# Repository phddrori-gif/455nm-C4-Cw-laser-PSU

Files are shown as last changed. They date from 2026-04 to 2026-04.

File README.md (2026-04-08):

# 455 nm 151 W Laser Array

## Overview
This repository documents the design, assembly, and testing of a 455 nm, 151 W diode laser array system built for high-power laser experimentation and materials research. The project combines optical, electrical, thermal, and safety engineering to create a controlled platform for evaluating laser performance and exploring laser-heated crystal growth.

## Project Objectives
- Achieve the full 151 W output of the diode array
- Explore laser-based growth of synthetic ruby
- Evaluate whether the system can be adapted for additional materials, including sapphire

## Current Status
The laser platform is operational in several core areas, with major progress completed in the safety, electrical, and mechanical subsystems. Remaining work is focused on characterization, documentation, and material-processing experiments.

## Safety Systems
Because this project involves a high-power 455 nm laser source, safety controls were treated as a primary design requirement.

Implemented safety features:
- OD8+ laser safety eyewear rated for 455 nm
- Hall-effect current sensing with ESP32-based monitoring
- Temperature-based automatic shutdown
- Emergency stop (E-stop)

## Mechanical and System Assembly
Completed design and integration work includes:
- 3D CAD model for the laser and circuit assembly
- Circuit design and schematic development
- PCB layout
- Custom lens holder
- Hybrid cooling system using both water cooling and forced-air cooling

## Electrical and Control Design
Completed electrical work:
- Tested PWM control and mechanical switch logic
- Verified full-wave rectifier suitability for 120 V AC input
- Integrated an IRM-05-3.3 power supply for the Teensy 4.0 controller
- Selected a 5.6 kOhm thermistor reference resistor based on a maximum expected operating temperature of 75 C

In progress:
- Fully label and reorganize the circuit diagram into clearly separated functional blocks

## Optical and Thermal Work
Completed:
- Selected a candidate focal length for the lens system (approximately +30 cm)

In progress:
- Determine the diode array's maximum allowable thermal load
- Measure and verify the optical power output of the diode array

## Materials and Crystal Growth Experiments
Completed:
- Acquired crucible for high-temperature material tests
- Acquired aluminum powder and chromium oxide for ruby experiments
- Planned work to be conducted in a fume hood

Planned:
- Acquire aluminum powder and iron oxide for sapphire experiments
- Evaluate the addition of titanium oxide for blue sapphire trials

## Next Steps
- Complete final circuit documentation
- Characterize thermal limits of the diode array
- Measure output power under controlled operating conditions
- Begin laser-heated ruby growth experiments
- Expand testing to additional materials if ruby trials are successful

## Resume Highlights
This project demonstrates experience in:
- High-power laser system integration
- Embedded monitoring and safety interlocks
- PCB and circuit design
- Thermal management
- Experimental hardware development
- Applied materials research

## Disclaimer
This repository documents work involving high-power laser equipment and high-temperature material processing. Testing should only be performed with proper protective equipment, controlled procedures, and appropriate lab safety infrastructure.

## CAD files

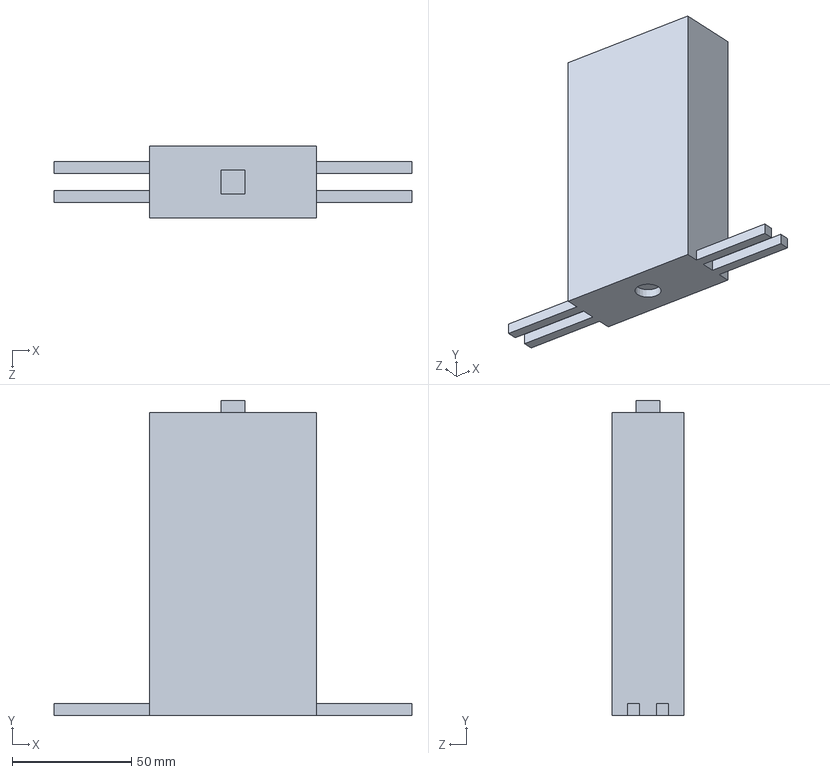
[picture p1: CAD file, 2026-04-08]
Laser Solidwork Files/Diode Base.SLDPRT
150.0 x 132.0 x 30.0 mm

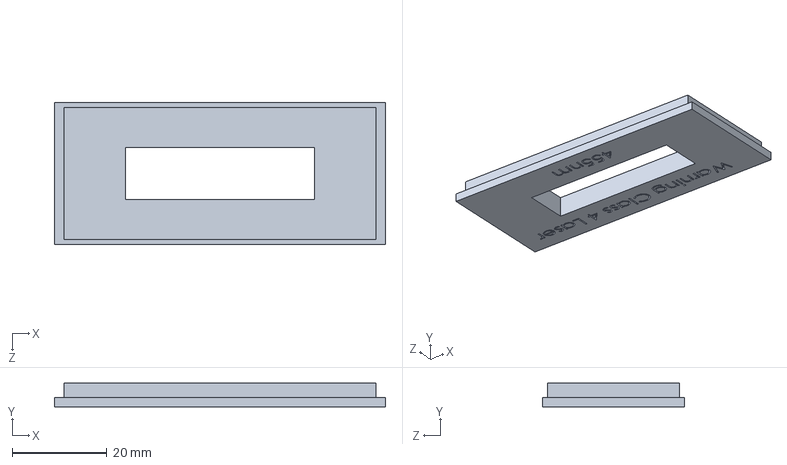
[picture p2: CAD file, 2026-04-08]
Laser Solidwork Files/Diode Holder Top.SLDPRT
70.0 x 5.00 x 30.0 mm

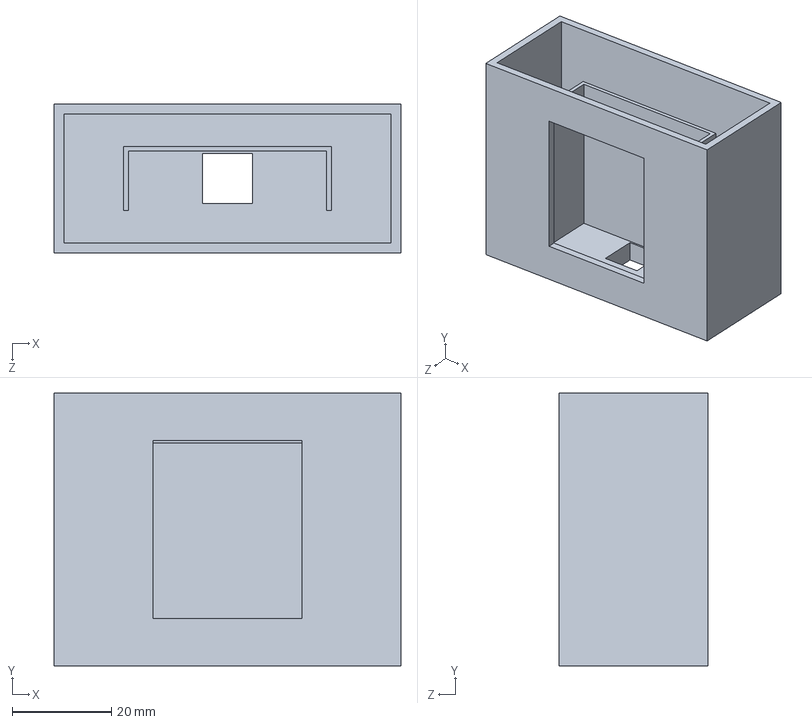
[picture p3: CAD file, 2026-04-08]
Laser Solidwork Files/Diode Holder.SLDPRT
70.0 x 55.0 x 30.0 mm

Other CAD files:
Laser Solidwork Files/Diode Base.STL
Laser Solidwork Files/Diode Holder Top.STL
Laser Solidwork Files/Diode Holder.STL

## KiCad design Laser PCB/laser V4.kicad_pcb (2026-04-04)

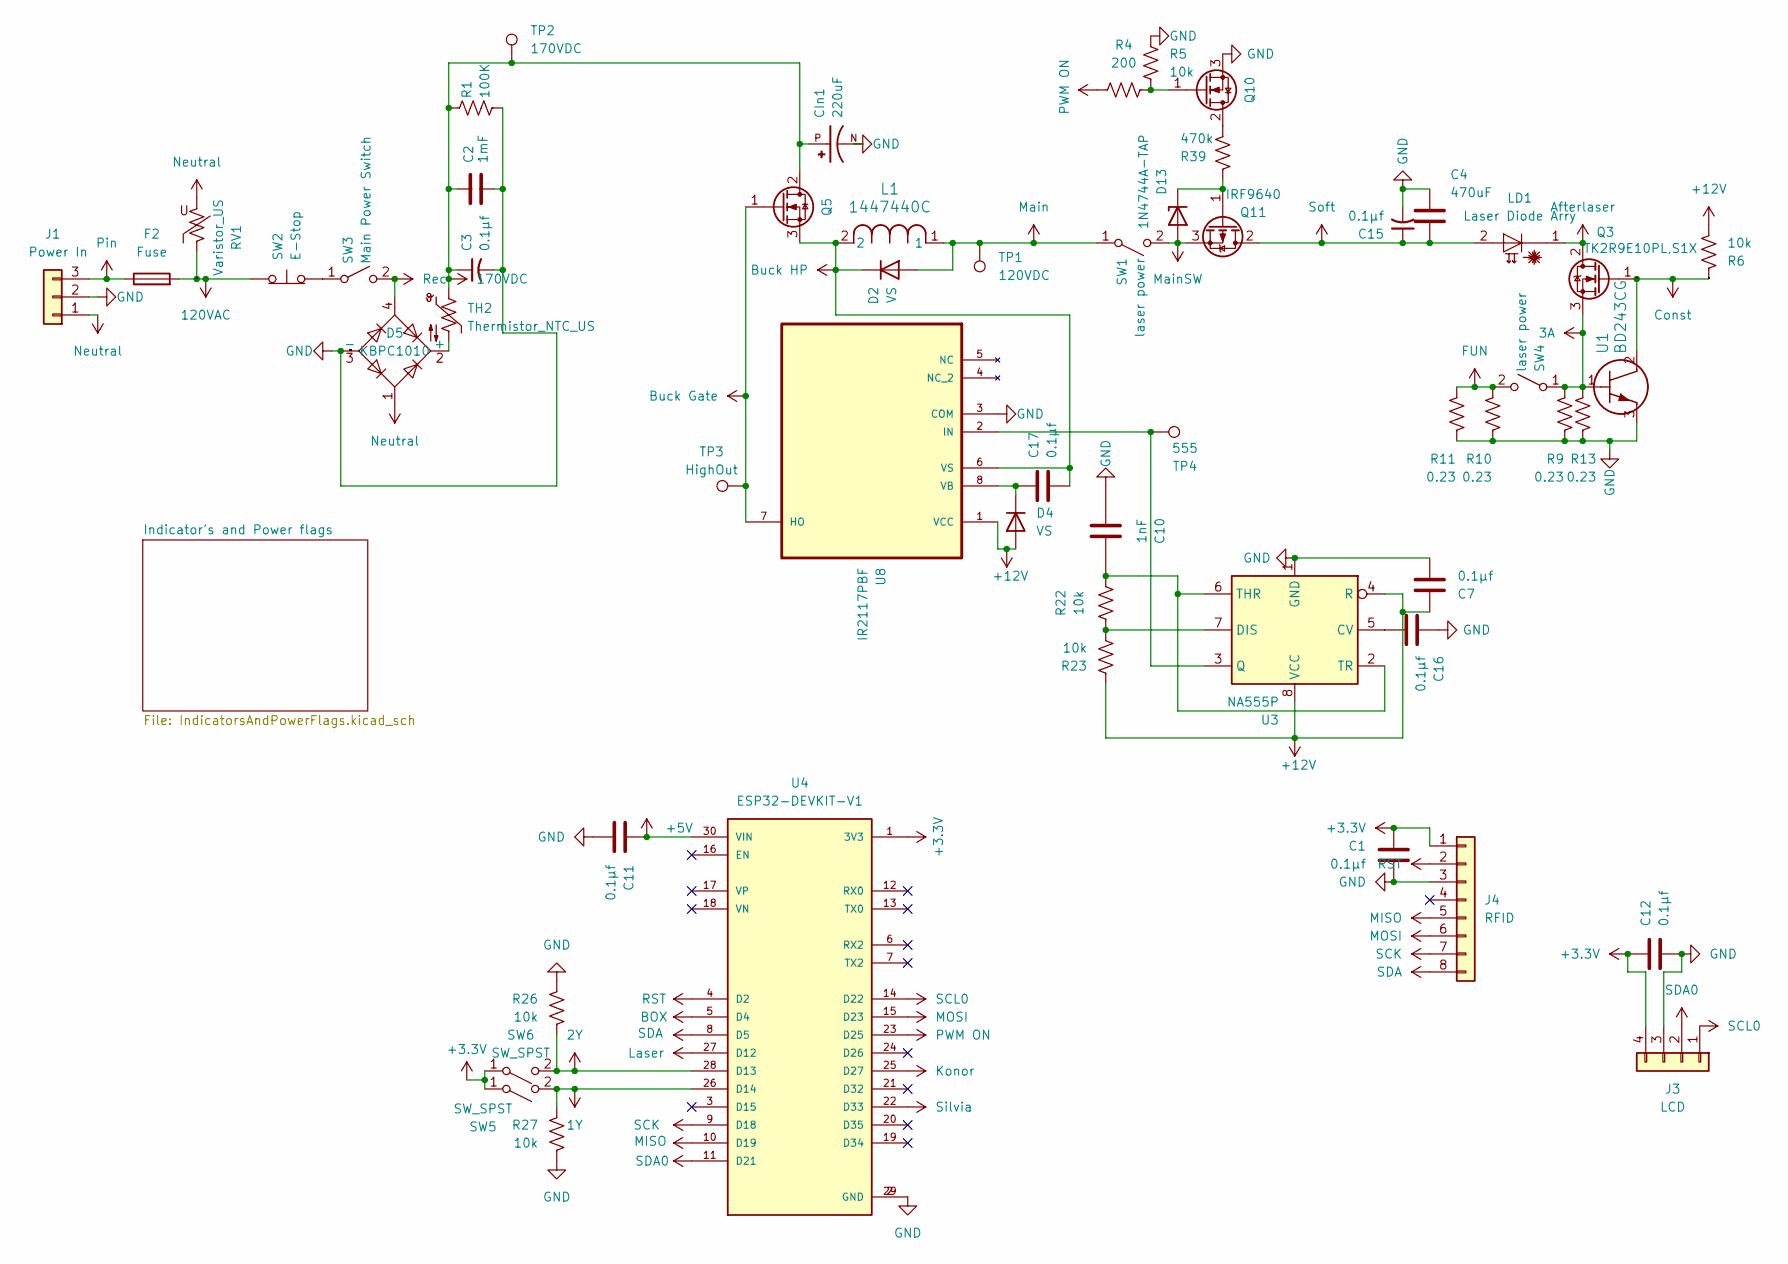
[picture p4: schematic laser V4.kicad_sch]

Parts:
C1, C7, C11, C12, C16, C17: 0.1µf; CP_Radial_D4.0mm_P2.00mm; Digikey 399-C320C104K5R5TA7305CT-ND
C2: 1mF; CP_Radial_D35.0mm_P10.00mm_SnapIn; Digikey 493-8541-ND
C3, C15: 0.1µf; CP_Radial_D4.0mm_P2.00mm; Digikey 399-3508-ND
C4: 470uF; CAPPRD500W60D1000H3150; Digikey 565-2971-ND
C10: 1nF; CP_Radial_D4.0mm_P2.00mm; Digikey 56-K102K15X7RF53H5G-ND
CIn1: 220uF; CAPPRD750W80D1600H3150; PARTREV 28-FEB-20; Digikey P13529-ND
D2, D4: VS; TO-220-2_Vertical; Digikey VS-HFA04TB60-M3GI-ND
D5: KBPC1010; Digikey 5272-KBPC1010-ND
D13: 1N4744A-TAP; D_DO-41_SOD81_P10.16mm_Horizontal; Digikey 1N4744A-TAPGICT-ND
F2: Fuse; Fuseholder_Clip-5x20mm_Littelfuse_100_Inline_P20.50x4.60mm_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; Digikey 486-4875-ND
J1: Power In; C14_thru hole
J3: LCD; FanPinHeader_1x04_P2.54mm_Vertical
J4: RFID; PinSocket_1x08_P2.54mm_Vertical
L1: 1447440C; 1447440C_MUR; Digikey 811-1332-ND
LD1: Laser Diode Arry; NUBM3D_LaserDiode_Pads
Q3: TK2R9E10PL,S1X; TO-220-3_Horizontal_TabUp; Digikey 264-TK2R9E10PL,S1X-ND
Q5, Q10: SIHP33N60E-GE3; TO-220-3_Horizontal_TabUp; Digikey 742-SIHP33N60E-GE3-ND
Q11: IRF9640; TO-220-3_Horizontal_TabUp; Digikey 742-IRF9640PBF-BE3-ND
R1: 100K; R_Axial_DIN0411_L9.9mm_D3.6mm_P12.70mm_Horizontal; Digikey A131429CT-ND
R4: 200; R_Axial_DIN0207_L6.3mm_D2.5mm_P10.16mm_Horizontal; Digikey RNF14FTD200RTR-ND
R5, R6, R22, R26, R27: 10k; R_Axial_DIN0207_L6.3mm_D2.5mm_P10.16mm_Horizontal; Digikey CF14JT10K0TR-ND
R9, R10, R11, R13: 0.23; R_Axial_Power_L20.0mm_W6.4mm_P25.40mm; Digikey A137272CT-ND
R23: 10k; R_Axial_DIN0207_L6.3mm_D2.5mm_P10.16mm_Horizontal; Digikey S3.3KQTR-ND
R39: 470k; R_Axial_DIN0207_L6.3mm_D2.5mm_P10.16mm_Horizontal
RV1: Varistor_US; VARRB750W81L1700T500H2250; DigiKey F4008-ND
SW1, SW4: laser power; TerminalBlock_WAGO_236-402_1x02_P5.00mm_45Degree; Digikey 708-3049-ND
SW2: E-Stop; TerminalBlock_WAGO_236-402_1x02_P5.00mm_45Degree
SW3: Main Power Switch; TerminalBlock_WAGO_236-402_1x02_P5.00mm_45Degree; Digikey 708-3049-ND
SW5, SW6: SW_SPST; PinHeader_1x02_P2.54mm_Vertical
TH2: Thermistor_NTC_US; RV_Disc_D21.5mm_W7.5mm_P10mm; Digikey 570-MS3220010-ND
TP1: 120VDC; TestPoint_Plated_Hole_D2.0mm
TP2: 170VDC; TestPoint_Plated_Hole_D2.0mm
TP3: HighOut; TestPoint_Plated_Hole_D2.0mm
TP4: 555; TestPoint_Plated_Hole_D2.0mm
U1: BD243CG; TO-220-3_Horizontal_TabUp; Digikey BD243CGOS-ND
U3: NA555P; DIP-8_W7.62mm; Digikey 296-21753-5-ND
U4: ESP32-DEVKIT-V1; MODULE_ESP32_DEVKIT_V1; PARTREV N/A
U8: IR2117PBF; DIP254P762X533-8; MPN IR2117PBF

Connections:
1Y: R27.1, SW5.2 (B), U4.26 (D14); also elsewhere on the board
2Y: R26.2, SW6.2 (B), U4.28 (D13); also elsewhere on the board
3A: Q3.3 (S), R9.1, R13.1, SW4.1 (A), U1.1
120VAC: F2.2, RV1.1, SW2.1 (A)
170VDC: C2.1, C3.1, CIn1.P, D5.2 (+), Q5.2 (D), R1.1, TH2.1, TH2.2, TP2.1; also elsewhere on the board
+3.3V: C1.1, C12.1, J3.4, J4.1, SW5.1 (A), SW6.1 (A), U4.1 (3V3); also elsewhere on the board
+5V: C11.1, U4.30 (VIN); also elsewhere on the board
+12V: C7.1, D4.2 (A), R6.2, R23.1, U3.4 (R), U3.8 (VCC), U8.1 (VCC); also elsewhere on the board
Afterlaser: LD1.1 (C), Q3.2 (D)
BOX: U4.5 (D4)
Buck Gate: Q5.1 (G), TP3.1, U8.7 (HO)
Buck HP: C17.2, D2.1 (K), L1.2, Q5.3 (S), U8.6 (VS)
Const: Q3.1 (G), R6.1, U1.2
FUN: R10.1, R11.1, SW4.2 (B); also elsewhere on the board
GND: C1.2, C2.2, C3.2, C4.1, C7.2, C10.2, C11.2, C12.2, C15.2, C16.1, CIn1.N, D5.3 (-), J1.2, J3.3, J4.3, Q10.3 (S), R1.2, R5.1, R9.2, R10.2, R11.2, R13.2, R26.1, R27.2, U1.3, U3.1 (GND), U4.2 (GND), U4.29 (GND), U8.3 (COM); also elsewhere on the board
Konor: U4.25 (D27); also elsewhere on the board
Laser: U4.27 (D12); also elsewhere on the board
MISO: J4.5, U4.10 (D19)
MOSI: J4.6, U4.15 (D23)
Main: D2.2 (A), L1.1, SW1.1 (A), TP1.1
MainSW: D13.2 (A), Q11.3 (S), SW1.2 (B)
unnamed: C17.1, D4.1 (K), U8.8 (VB)
unnamed: D13.1 (K), Q11.1 (G), R39.1
unnamed: Q10.2 (D), R39.2
unnamed: Q10.1 (G), R4.2, R5.2
unnamed: SW2.2 (B), SW3.1 (A)
unnamed: C16.2, U3.5 (CV)
unnamed: R22.2, R23.2, U3.7 (DIS)
unnamed: TP4.1, U3.3 (Q), U8.2 (IN)
unnamed: C10.1, R22.1, U3.2 (TR), U3.6 (THR)
Neutral: D5.1, J1.1, RV1.2; also elsewhere on the board
PWM ON: R4.1, U4.23 (D25)
Pin: F2.1, J1.3; also elsewhere on the board
RST: J4.2, U4.4 (D2)
Rec: D5.4, SW3.2 (B)
SCK: J4.7, U4.9 (D18)
SCL0: J3.1, U4.14 (D22)
SDA: J4.8, U4.8 (D5)
SDA0: J3.2, U4.11 (D21)
Silvia: U4.22 (D33); also elsewhere on the board
Soft: C4.2, C15.1, LD1.2 (A), Q11.2 (D)

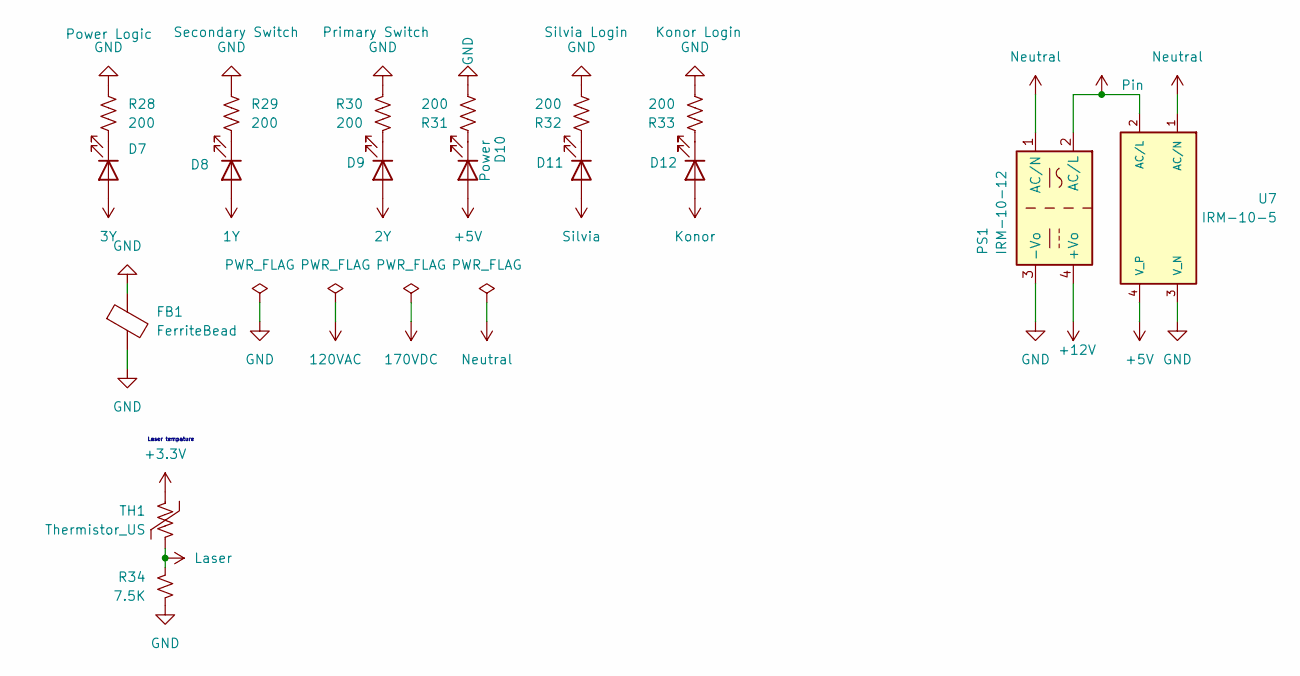
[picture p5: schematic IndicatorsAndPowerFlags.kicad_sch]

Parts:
D7: Power Logic; LED_D5.0mm; Digikey 732-5016-ND
D8: Secondary Switch; LED_D5.0mm; Digikey 732-5016-ND
D9: Primary Switch; LED_D5.0mm; Digikey 732-5016-ND
D10: Power; LED_D5.0mm; Digikey 732-5016-ND
D11: Silvia Login; LED_D5.0mm; Digikey 732-5016-ND
D12: Konor Login; LED_D5.0mm; Digikey 732-5016-ND
FB1: FerriteBead; R_Axial_DIN0207_L6.3mm_D2.5mm_P7.62mm_Horizontal; Digikey 1934-1476-2-ND
PS1: IRM-10-12; Converter_ACDC_MeanWell_IRM-10-xx_THT; Digikey 1866-3028-ND
R28, R29, R30, R31, R32, R33: 200; R_Axial_DIN0207_L6.3mm_D2.5mm_P10.16mm_Horizontal; Digikey RNF14FTD200RTR-ND
R34: 7.5K; R_Axial_DIN0207_L6.3mm_D2.5mm_P10.16mm_Horizontal
TH1: Thermistor_US; PinHeader_1x02_P2.54mm_Vertical; Digikey 317-1258-ND
U7: IRM-10-5; CONV_IRM-10-5; Digikey 1866-3032-ND

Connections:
1Y: D8.2 (A); also elsewhere on the board
2Y: D9.2 (A); also elsewhere on the board
3Y: D7.2 (A)
+3.3V: TH1.1; also elsewhere on the board
+5V: D10.2 (A), U7.4 (V_P); also elsewhere on the board
+12V: PS1.4 (+Vo); also elsewhere on the board
GND: FB1.1, FB1.2, PS1.3 (-Vo), R28.1, R29.2, R30.1, R31.2, R32.2, R33.2, R34.1, U7.3 (V_N); also elsewhere on the board
Konor: D12.2 (A); also elsewhere on the board
Laser: R34.2, TH1.2; also elsewhere on the board
unnamed: D7.1 (K), R28.2
unnamed: D8.1 (K), R29.1
unnamed: D9.1 (K), R30.2
unnamed: D10.1 (K), R31.1
unnamed: D11.1 (K), R32.1
unnamed: D12.1 (K), R33.1
Neutral: PS1.1 (AC/N), U7.1 (AC/N); also elsewhere on the board
Pin: PS1.2 (AC/L), U7.2 (AC/L); also elsewhere on the board
Silvia: D11.2 (A); also elsewhere on the board

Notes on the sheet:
Laser tempature

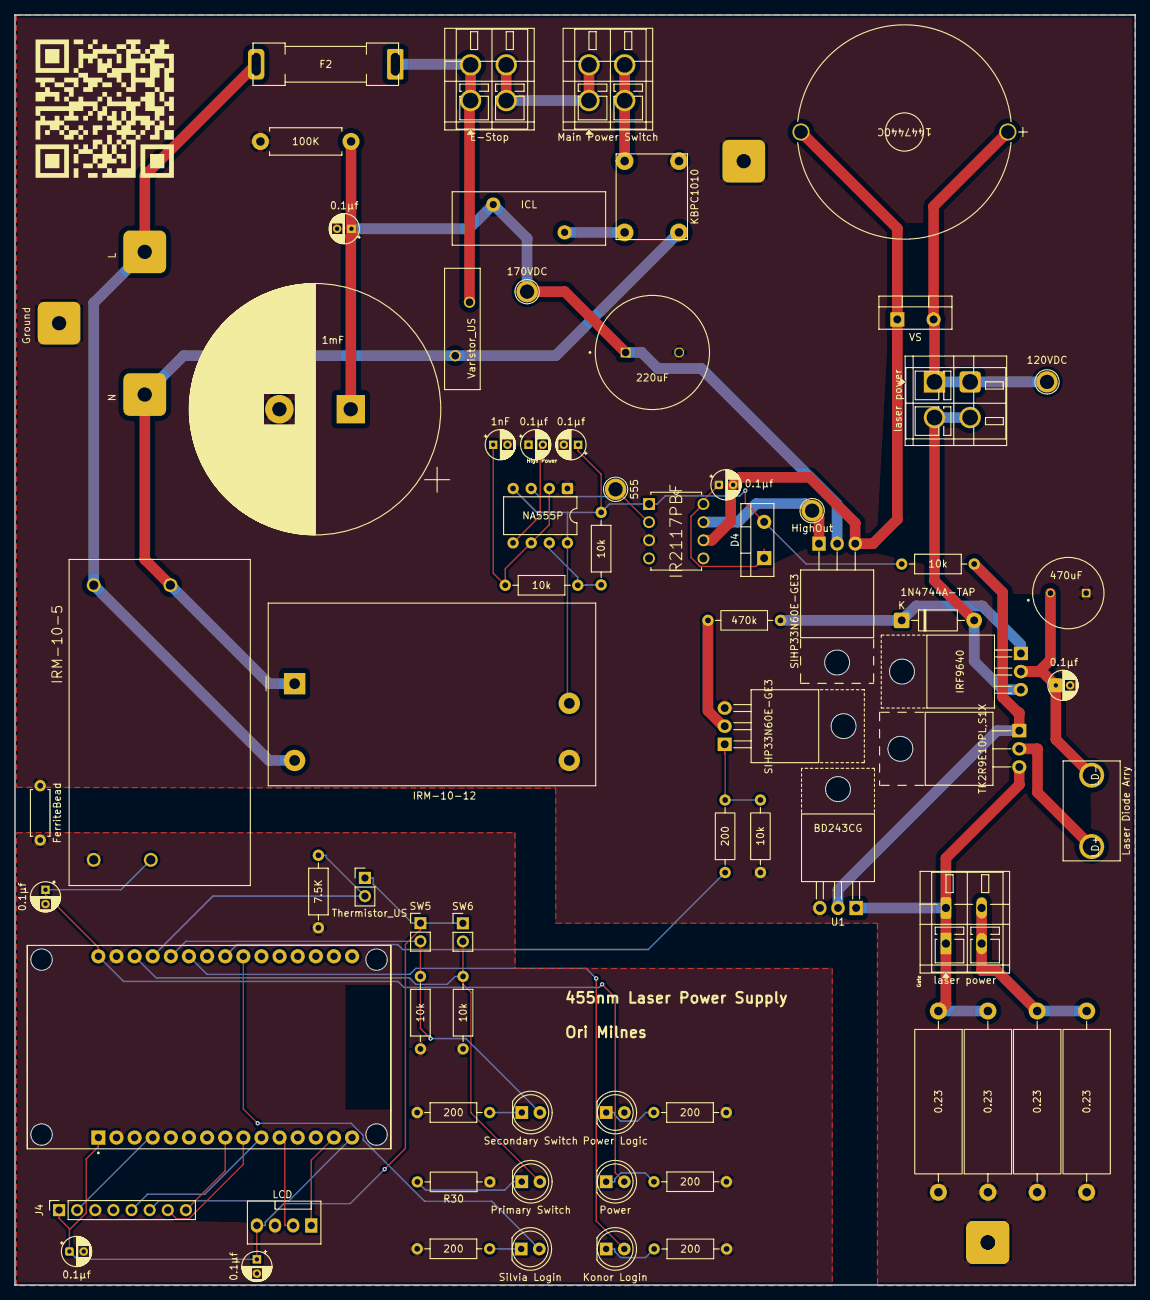
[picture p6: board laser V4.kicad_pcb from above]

Board: 2 copper layers, 157.0 x 178.0 mm, 73 parts (0 on the bottom side), 46 nets.

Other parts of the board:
0.23, 0.23#2: 0.23; R_Axial_Power_L20.0mm_W6.4mm_P25.40mm
G1: LOGO
ICL: Thermistor_NTC_US; RV_Disc_D21.5mm_W7.5mm_P10mm

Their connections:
170VDC: ICL.1, ICL.2; also elsewhere on the board
FUN: 0.23.1, 0.23#2.1; also elsewhere on the board
GND: 0.23.2, 0.23#2.2; also elsewhere on the board

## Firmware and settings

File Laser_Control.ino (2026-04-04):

#include <Wire.h>
#include <SPI.h>
#include <MFRC522.h>
#include <LiquidCrystal_I2C.h>
#include <math.h>
#include <Watchdog_t4.h>

WDT_T4<WDT1> wdt;

// RFID RC522
#define RST_PIN 9
#define SS_PIN 10
MFRC522 mfrc522(SS_PIN, RST_PIN);

// LCD I2C
LiquidCrystal_I2C lcd(0x27, 16, 2);

// Known UIDs
const byte UID_A[] = { 0x73, 0xD6, 0xEE, 0xAE };  // KONOR
const byte UID_B[] = { 0x53, 0x77, 0xAB, 0x98 };  // SILVIA
const byte UID_A_LEN = sizeof(UID_A);
const byte UID_B_LEN = sizeof(UID_B);

// Pins
const int THERMISTOR_LASER_PIN  = A0;  // pin 14
const int THERMISTOR_MOSFET_PIN = A3;  // pin 17
const int VOLTAGE1_PIN   = A1;  // pin 15
const int VOLTAGE2_PIN   = A2;  // pin 16
const int CURRENT_PIN    = A8;  // pin 22
const int PWM_LASER_PIN  = 23;
const int PWM_ON_PIN     = 8;
const int KONOR_LED_PIN  = 6;
const int SILVIA_LED_PIN = 7;

// Constants
const float ADC_REF = 3.3;
const int ADC_RES = 4095;
const float SHUNT_RESISTANCE = 0.1;
const float VOLT_DIV_RATIO_1 = 57.0;
const float VOLT_DIV_RATIO_2 = 37.0;

// System State
bool isA_loggedIn = false;
bool isB_loggedIn = false;
bool isLocked = false;
bool inCooldown = false;
int unknownScanCount = 0;
int pwmLaserValue = 255;  // default 100%

// Override
bool overrideMode = false;
unsigned long overrideStartTime = 0;
const unsigned long overrideDuration = 60000;
unsigned long lastUIDScanTime = 0;
const unsigned long overrideScanWindow = 3000;
byte lastUID[10];
byte lastUIDLen = 0;

// Timing
unsigned long lastVoltageSwitch = 0;
unsigned long lastDisplayUpdate = 0;
unsigned long cooldownStart = 0;
const unsigned long voltageSwitchInterval = 5000;
const unsigned long displayInterval = 200;
const unsigned long cooldownDuration = 60000;
bool showVoltage1 = true;

// Soft start
unsigned long softStartStartTime = 0;
const unsigned long softStartDuration = 5000;  // 5 seconds

void setup() {
  Serial.begin(115200);
  analogReadResolution(12);
  analogReadAveraging(8);
  pinMode(PWM_LASER_PIN, OUTPUT);
  pinMode(PWM_ON_PIN, OUTPUT);
  pinMode(KONOR_LED_PIN, OUTPUT);
  pinMode(SILVIA_LED_PIN, OUTPUT);
  analogWrite(PWM_LASER_PIN, 0);
  analogWrite(PWM_ON_PIN, 0);

  WDT_timings_t config = {
    .trigger = 8000,
    .timeout = 16000,
    .callback = nullptr
  };
  wdt.begin(config);

  lcd.init();
  lcd.backlight();
  lcd.setCursor(0, 0);
  lcd.print("LCD OK...");
  delay(500);

  SPI.begin();
  mfrc522.PCD_Init();
  delay(100);
  lcd.clear();
  lcd.print("RFID Ready");
  delay(1000);
  lcd.clear();
}

void loop() {
  wdt.feed();

  static int lastPwmOnValue = -1;
  static int lastLaserPwmValue = -1;
  static bool lastPwmOn = false;

  digitalWrite(KONOR_LED_PIN, isA_loggedIn);
  digitalWrite(SILVIA_LED_PIN, isB_loggedIn);

  float tempC = readTemperature(THERMISTOR_LASER_PIN);
  if ((tempC >= 60.0 || tempC > 150.0) && !inCooldown) enterCooldown("TEMP ERROR");
  if (inCooldown) { handleCooldown(); return; }

  if (Serial.available()) {
    int input = Serial.parseInt();
    if (input >= 0 && input <= 255) {
      pwmLaserValue = input;
    }
  }

  // RFID logic
  if (mfrc522.PICC_IsNewCardPresent() && mfrc522.PICC_ReadCardSerial()) {
    byte* uid = mfrc522.uid.uidByte;
    byte uidLen = mfrc522.uid.size;
    unsigned long now = millis();

    if (compareUID(uid, uidLen, UID_A, UID_A_LEN)) {
      if (lastUIDLen == UID_A_LEN && compareUID(uid, uidLen, lastUID, lastUIDLen)) {
        if (now - lastUIDScanTime <= overrideScanWindow) {
          overrideMode = true;
          overrideStartTime = now;
          softStartStartTime = now;
          lcd.clear();
          lcd.setCursor(0, 0);
          lcd.print("OVERRIDE MODE");
          delay(1000);
          lcd.clear();
        }
      }
      memcpy(lastUID, uid, uidLen);
      lastUIDLen = uidLen;
      lastUIDScanTime = now;
    }

    if (compareUID(uid, uidLen, UID_A, UID_A_LEN)) {
      isA_loggedIn = !isA_loggedIn;
      unknownScanCount = 0;
    } else if (compareUID(uid, uidLen, UID_B, UID_B_LEN)) {
      if (!isLocked) {
        isB_loggedIn = !isB_loggedIn;
        unknownScanCount = 0;
      }
    } else {
      unknownScanCount++;
      if (unknownScanCount >= 2) {
        isA_loggedIn = false;
        isB_loggedIn = false;
        isLocked = true;
      }
    }

    mfrc522.PICC_HaltA();
  }

  if (overrideMode && millis() - overrideStartTime > overrideDuration) {
    overrideMode = false;
  }

  float currentVoltage = analogRead(CURRENT_PIN) * (ADC_REF / ADC_RES);
  float currentAmps = currentVoltage / SHUNT_RESISTANCE;
  float voltage1 = analogRead(VOLTAGE1_PIN) * (ADC_REF / ADC_RES) * VOLT_DIV_RATIO_1;
  float voltage2 = analogRead(VOLTAGE2_PIN) * (ADC_REF / ADC_RES) * VOLT_DIV_RATIO_2;

  bool pwmOn = ((isA_loggedIn && isB_loggedIn) || overrideMode) && !isLocked;

  // Detect rising edge for soft start
  if (pwmOn && !lastPwmOn) {
    softStartStartTime = millis();
  }
  lastPwmOn = pwmOn;

  // Soft-start PWM (pin 8)
  int pwmOnValue = 0;
  if (pwmOn) {
    unsigned long elapsed = millis() - softStartStartTime;
    pwmOnValue = (elapsed >= softStartDuration) ? 255 : map(elapsed, 0, softStartDuration, 0, 255);
  } else {
    pwmOnValue = 0;
  }
  if (pwmOnValue != lastPwmOnValue) {
    analogWrite(PWM_ON_PIN, pwmOnValue);
    lastPwmOnValue = pwmOnValue;
  }

  // Laser PWM (pin 23)
  int laserPwmValue = (pwmOn ? pwmLaserValue : 0);
  if (laserPwmValue != lastLaserPwmValue) {
    analogWrite(PWM_LASER_PIN, laserPwmValue);
    lastLaserPwmValue = laserPwmValue;
  }

  // Display control
  if (millis() - lastVoltageSwitch > voltageSwitchInterval) {
    showVoltage1 = !showVoltage1;
    lastVoltageSwitch = millis();
  }

  if (millis() - lastDisplayUpdate >= displayInterval) {
    lcd.setCursor(0, 0);

    if (overrideMode) {
      lcd.print("OVERRIDE MODE   ");
      lcd.setCursor(0, 1);
      unsigned long remaining = (overrideDuration - (millis() - overrideStartTime)) / 1000;
      lcd.print("Time Left: ");
      if (remaining < 10) lcd.print(" ");
      lcd.print(remaining);
      lcd.print("s   ");
    } else if (pwmOn) {
      lcd.print("POWER:ON  PWM:");
      lcd.print((int)(pwmLaserValue * 100 / 255));
      lcd.print("% ");
      lcd.setCursor(0, 1);
      float displayV = showVoltage1 ? voltage1 : voltage2;
      lcd.print(showVoltage1 ? "V1:" : "V2:");
      lcd.print((int)displayV);
      if (displayV < 100) lcd.print(" ");
      if (displayV < 10) lcd.print(" ");
      lcd.print(" ");
      printFixed(lcd, currentAmps, 3, 1);
      lcd.print("A");
    } else {
      lcd.print("Silvia:");
      lcd.print(isB_loggedIn ? "Y " : "N ");
      lcd.print("Konor:");
      lcd.print(isA_loggedIn ? "Y" : "N ");
      lcd.print("   ");
      lcd.setCursor(0, 1);
      float displayV = showVoltage1 ? voltage1 : voltage2;
      lcd.print(showVoltage1 ? "V1:" : "V2:");
      lcd.print((int)displayV);
      if (displayV < 100) lcd.print(" ");
      if (displayV < 10) lcd.print(" ");
      lcd.print(" ");
      printFixed(lcd, currentAmps, 3, 1);
      lcd.print("A");
    }

    lastDisplayUpdate = millis();
  }
}

float readTemperature(int pin) {
  const float Vcc = 3.3;
  const float R_FIXED = 10000.0;
  const float BETA = 3950.0;
  const float T0 = 298.15;
  int raw = analogRead(pin);
  if (raw < 5 || raw > 4090) return 999.0;
  float Vout = raw * (Vcc / ADC_RES);
  float R_therm = R_FIXED * ((Vcc / Vout) - 1.0);
  float tempK = 1.0 / (log(R_therm / R_FIXED) / BETA + (1.0 / T0));
  return tempK - 273.15;
}

bool compareUID(const byte *uid1, byte len1, const byte *uid2, byte len2) {
  if (len1 != len2) return false;
  for (byte i = 0; i < len1; i++) {
    if (uid1[i] != uid2[i]) return false;
  }
  return true;
}

void enterCooldown(const char* reason) {
  isA_loggedIn = false;
  isB_loggedIn = false;
  isLocked = true;
  inCooldown = true;
  overrideMode = false;
  analogWrite(PWM_LASER_PIN, 0);
  analogWrite(PWM_ON_PIN, 0);
  lcd.clear();
  lcd.setCursor(0, 0);
  lcd.print(reason);
  cooldownStart = millis();
}

void handleCooldown() {
  unsigned long elapsed = millis() - cooldownStart;
  unsigned long remaining = (cooldownDuration - elapsed) / 1000;
  lcd.setCursor(0, 1);
  lcd.print("Cooldown: ");
  if (remaining < 10) lcd.print(" ");
  lcd.print(remaining);
  lcd.print("s   ");
  if (elapsed >= cooldownDuration) {
    inCooldown = false;
    isLocked = false;
    lcd.clear();
    lcd.print("Cooldown done");
    delay(1000);
    lcd.clear();
  }
}

void printFixed(LiquidCrystal_I2C &lcd, float value, int digits, int decimals) {
  char buffer[8];
  dtostrf(value, digits + decimals + 1, decimals, buffer);
  lcd.print(buffer);
}

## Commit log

2026-04-08 naming clarification
    [IndicatorsAndPowerFlags.kicad_sch, laser V3.kicad_sch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]
2026-04-08 added solidwork files
    [Diode Base.SLDPRT, Diode Base.STL, Diode Holder Top.SLDPRT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]
